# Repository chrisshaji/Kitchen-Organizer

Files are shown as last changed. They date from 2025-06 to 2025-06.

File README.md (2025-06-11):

# Kitchen-Organizer
A customized and portable Kitchen utensil organizer.

## Design Rationale
My friend had reached out to me to ask me if I could make a drawer for his kitchen to hold all of his spatulas and cookware. We decided on 3D printing one as
it would be very cost-effective, and easy to fabricate. One major constraint we had to keep in mind was the size of the drawer. Since we wanted the holder to 
fit nice and snug in the drawer, it had to be about the length of the drawer which was about 15 inches. We had to do some thinking in order to fabricate this as 
it was too big for any 3D printer to print in one piece. We brainstormed and finally ended up with breaking the holder into two pieces and connecting them using 
snap in joints.

|  3D model of the part| Test snap in joints |  Kitchen holder in use |
| :---:  | :---: | :---: |
| 3D model of the part | Test snap in joints | Kitchen holder in use |

Designing the snap in joints was harder than expected. We experimented with number of snap in joints, length, number of hooks, tolerancing etc. Initially, we went for 4 snap in
joints, but after testing, it proved to be hard to disconect once joined, so we decided on using 2 snap in joints on either side as shown below. One counterintuitive thing about 
it was to decrease the thickness and increase their length. While it make them slightly weaker, it was essential that the snap in joints were thin enough to provide the necessary
flexure needed for repeatable use. We arrived at our final iteration of snap in joints after lots of testing and tolerancing. It was 3D printed at the Mechanical Engineering
Rapid Prototyping Studio (RPS) at Texas A&M with PLA, 25% infill, 3 walls, and tree supports.

<p align="center">
  Top-down view of the kitchen holder with some utensils
  <br/>
  <em>Top-down view of the kitchen holder with some utensils</em>
</p>

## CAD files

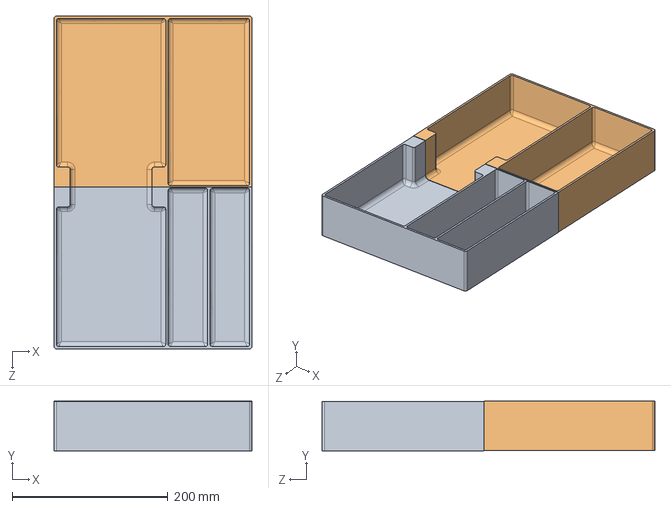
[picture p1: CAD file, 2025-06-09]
KD Assem.SLDASM
254.0 x 63.8 x 426.9 mm
Kitchen Drawer Holder_NEWMODEL-Split2
Kitchen Drawer Holder_NEWMODEL-Split1

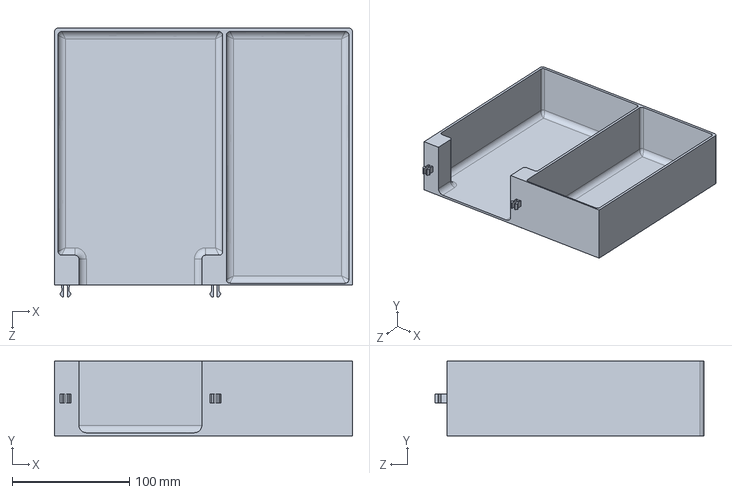
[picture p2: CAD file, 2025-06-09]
Kitchen Drawer Holder_NEWMODEL-Split2.SLDPRT
254.0 x 63.5 x 229.2 mm

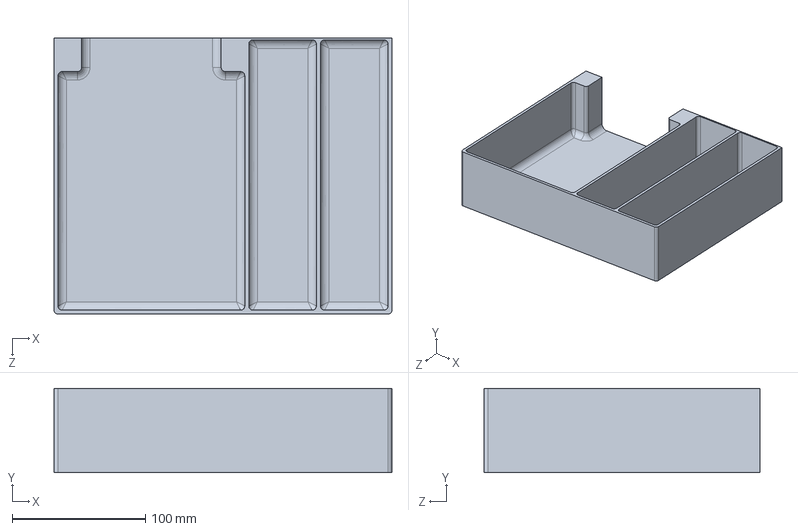
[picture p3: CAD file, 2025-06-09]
Kitchen Drawer Holder_NEWMODEL-Split1.SLDPRT
254.0 x 63.5 x 207.7 mm
